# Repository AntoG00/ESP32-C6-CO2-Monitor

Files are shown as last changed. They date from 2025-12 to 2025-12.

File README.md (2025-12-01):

# ESP32-C6 E-Paper Air Quality Monitor

A high-precision, open-hardware environmental monitor designed to track CO2, Temperature, and Humidity levels. The device is built around the RISC-V based ESP32-C6 and features a raw E-Paper panel with a custom-designed boost driver to ensure zero light pollution and minimal thermal self-heating.

Schematic
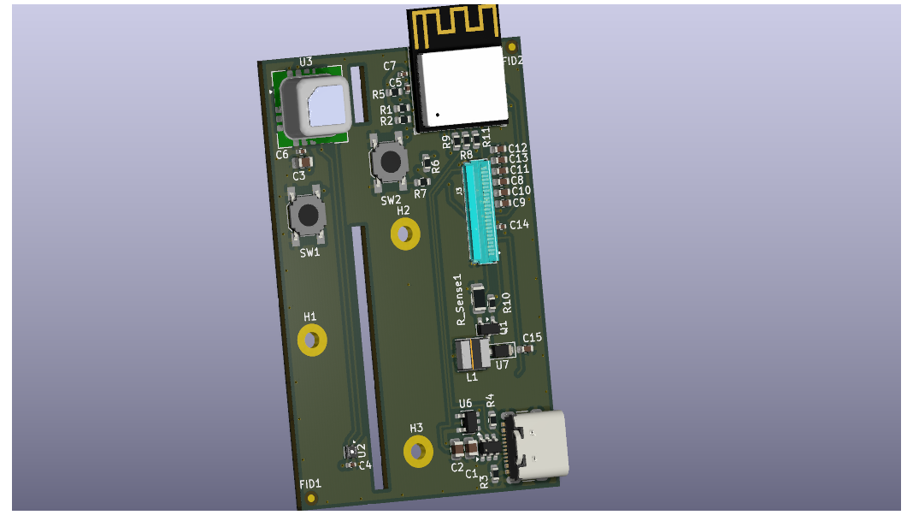
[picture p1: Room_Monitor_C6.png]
3D Render of the PCB


## Key Features
*   **MCU:** Espressif **ESP32-C6-Mini-1** (RISC-V, Wi-Fi 6, BLE 5, Zigbee).
*   **Sensors:**
    *   **SCD43 (Sensirion):** Photoacoustic NDIR CO2 sensor for high-accuracy indoor air quality monitoring.
    *   **SHT45-AD1F (Sensirion):** Ultra-high precision (±1.0% RH, ±0.1°C) temperature and humidity sensor with integrated PTFE membrane for protection.
*   **Display:** **Pervasive Displays E2266QS0F1** (2.66" E-Paper/E-Ink).
*   **Power:** USB-C powered via a high-efficiency, low-noise LDO (**TLV75733**). Designed for continuous operation without batteries.

## Engineering Design Decisions
This project involved several specific hardware design challenges:

1.  **Thermal Isolation (Mechanical/Electrical):** To prevent the heat generated by the MCU and voltage regulators from biasing the sensitive SHT45 and SCD43 readings, the sensors are physically isolated on the PCB using milling slots (thermal cutouts) and thin connecting bridges.
2.  **Custom E-Paper Driver:** Instead of using a pre-made display module, I integrated the high-voltage boost converter (generating ~15V) directly onto the main PCB using a specialized power inductor ($I_{sat} > 800mA$), N-Channel MOSFET, and Schottky diode topology.
3.  **Signal Integrity:** The schematic includes specific filtering for the photoacoustic sensor's peak current demands and a dedicated boot-strapping circuit to ensure reliable flashing via the native USB interface.

## PCB Layout & Thermal Engineering
The design utilizes a **4-layer stack-up** to ensure solid Ground return paths and stable power delivery for the ESP32's RF radio.

A dedicated **thermal isolation slot** separates the board into two distinct thermal zones:
*   **Right Side (Hot Zone):** Contains the ESP32 MCU, Power Regulation, and Boost Converter.
*   **Left Side (Cold Zone):** Contains the environmental sensors, connected only by narrow FR4 bridges to minimize thermal conductivity.

## Status
*   [x] Schematic Design & Verification
*   [x] PCB Layout (4-Layer)
*   [ ] Manufacturing & Assembly

## License
MIT License

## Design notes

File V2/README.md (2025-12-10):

# Hardware V2 – ESP32‑C6 + SEN66 + 4.2" E‑Ink

This is the second hardware revision of the project. V2 replaces the SCD43 + SHT45 combo with a single Sensirion **SEN66** environmental sensor and upgrades the display.

## Main Components

- **MCU:** Espressif **ESP32‑C6 Mini**
  - Wi‑Fi 6 + BLE / 802.15.4 capable (WiFi 6, Zigbee, Thread)
- **Sensor:** Sensirion **SEN66**
  - PM1, PM2.5, PM4, PM10
  - Temperature, Relative Humidity
  - VOC Index, NOx Index, CO₂
- **Display:** Pervasive Displays **4.2" Spectra E2417QS0A3**
  - 3‑color E‑Ink
- **Status LED:** Inolux **IN‑PI33TBTPRPGPB** multi‑color LED
  - Used for debug / status indication via color patterns

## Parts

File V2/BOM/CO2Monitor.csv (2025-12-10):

Reference | Qty | Value | DNP | Exclude from BOM | Exclude from Board | Footprint | Datasheet
C1,C2,C3,C4,C5,C6,C7,C13 | 8 | 1µF 50V |  |  |  | Capacitor_SMD:C_0603_1608Metric | ~
C8,C9 | 2 | 4.7µF 25V |  |  |  | Capacitor_SMD:C_1206_3216Metric | ~
C10,C12,C15,C17,C18 | 5 | 0.1µF 16V |  |  |  | Capacitor_SMD:C_0402_1005Metric | ~
C11,C14,C16 | 3 | 10µF 16V |  |  |  | Capacitor_SMD:C_0805_2012Metric | ~
C19,C20 | 2 | 22µF 10V |  |  |  | Capacitor_SMD:C_1206_3216Metric | ~
D1,D2,D3 | 3 | SS2040FL |  |  |  | SS2040FL:SODFL3618X110N | https://4donline.ihs.com/images/VipMasterIC/IC/PNJI/PNJI-S-A0003671102/PNJI-S-A0003671102-1.pdf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
D4 | 1 | IN-PI33TBTPRPGPB |  |  |  | IN-PI33TBTPRPGPB:LED_IN-PI33TBTPRPGPB
H1,H2,H3 | 3 | MountingHole_Pad |  | Excluded from BOM |  | MountingHole:MountingHole_3.2mm_M3_ISO14580_Pad | ~
J1 | 1 | FH34SRJ-24S-0.5SH50 |  |  |  | FH34SRJ-24S-0.5SH(50):CONN24x1_FH34SRJ-24S-0.5SH50_HIR | FH34SRJ-24S-0.5SH50
J2 | 1 | USB_C_Receptacle_USB2.0_16P |  |  |  | USB4145-03-0230-C:GCT_USB4145-03-0230-C_REVA2 | https://www.usb.org/sites/default/files/documents/usb_type-c.zip
J3 | 1 | Conn_01x06 |  |  |  | Connector_JST:JST_GH_SM06B-GHS-TB_1x06-1MP_P1.25mm_Horizontal | ~
L1 | 1 | 10 uH |  |  |  | Inductor_SMD:L_Bourns-SRN4018 | ~
L2 | 1 | 3.9 uH |  |  |  | Inductor_SMD:L_Bourns-SRN4018 | ~
Q1 | 1 | Si1308EDL |  |  |  | Package_TO_SOT_SMD:SOT-323_SC-70 | https://www.vishay.com/docs/63399/si1308edl.pdf
Q2 | 1 | SI2301-TP |  |  |  | SI2301-TP:SOT95P237X125-3N | https://mccsemi.com/pdf/Products/SI2301(SOT-23).pdf
R1 | 1 | 0.47Ω 1% |  |  |  | Resistor_SMD:R_1206_3216Metric | ~
R2 | 1 | 100kΩ |  |  |  | Resistor_SMD:R_0603_1608Metric | ~
R3,R4 | 2 | 5.1kΩ |  |  |  | Resistor_SMD:R_0603_1608Metric | ~
R5,R6,R7,R8,R11,R12 | 6 | 10kΩ |  |  |  | Resistor_SMD:R_0603_1608Metric | ~
R9,R10,R14 | 3 | 22Ω |  |  |  | Resistor_SMD:R_0603_1608Metric | ~
R13 | 1 | 1kΩ |  |  |  | Resistor_SMD:R_0603_1608Metric | ~
SW1,SW2 | 2 | 2-1437565-8 |  |  |  | TE Connectivity 2-1437565-8:SW_2-1437565-8
U1 | 1 | USBLC6-2SC6 |  |  |  | Package_TO_SOT_SMD:SOT-23-6 | https://www.st.com/resource/en/datasheet/usblc6-2.pdf
U2 | 1 | SN74AHCT1G125DBVR |  |  |  | SN74AHCT1G125DBVR:SOT95P280X145-5N
U3 | 1 | AP63203WU |  |  |  | Package_TO_SOT_SMD:TSOT-23-6 | https://www.diodes.com/assets/Datasheets/AP63200-AP63201-AP63203-AP63205.pdf
U4 | 1 | ESP32-C6-MINI-1/U |  |  |  | PCM_Espressif:ESP32-C6-MINI-1 | https://www.espressif.com/sites/default/files/documentation/esp32-c6-mini-1_datasheet_en.pdf

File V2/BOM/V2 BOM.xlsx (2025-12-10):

 |  |  | BOM
Item # | *Designator | *Qty | Manufacturer | *Mfg Part # | Description / Value | *Package/Footprint | Your Instructions / Notes
1 | C1,C2,C3,C4,C5,C6,C7,C13 | 8 |  | 1µF 50V | Cap Ceramic 1µF 50V X7R 10% | Capacitor_SMD:C_0603_1608Metric
2 | C8,C9 | 2 |  | 4.7µF 25V | Cap Ceramic 4.7µF 25V X7R 10% | Capacitor_SMD:C_1206_3216Metric
3 | C10,C12,C15,C17,C18 | 5 |  | 0.1µF 16V | Cap Ceramic 0.1µF 16V (or 25V) X7R 10% | Capacitor_SMD:C_0402_1005Metric
4 | C11,C14,C16 | 3 |  | 10µF 16V | Cap Ceramic 10µF 16V (or 25V) X5R/X7R 10% | Capacitor_SMD:C_0805_2012Metric
5 | C19,C20 | 2 |  | 22µF 10V | Cap Ceramic 22µF 10V (or 16V) X5R/X7R 20% | Capacitor_SMD:C_1206_3216Metric
6 | D1,D2,D3 | 3 | Panjit | SS2040FL_R1_00001 | Schottky Diodes & Rectifiers 40V,Schottky,SOD-123FL,2A | SS2040FL:SODFL3618X110N | https://www2.mouser.com/datasheet/3/3736/1/774A80C0874A6CB8090245F2BB384B93521894600CCD1BA14FFDA33ECB6A733A.pdf
7 | D4 | 1 | Inolux | IN-PI33TBTPRPGPB | Multi-Colour LEDs Top View / PLCC / 3.5 x 3.5 x 1.95 / 4-pin / Tricolor with IC | IN-PI33TBTPRPGPB:LED_IN-PI33TBTPRPGPB | https://www2.mouser.com/datasheet/3/760/1/IN_PI33TBTPRPGPB_v1.2.pdf
8 | J1 | 1 | Hirose Connector | FH34SRJ-24S-0.5SH50 | FFC & FPC Connectors 24POS .5MM | FH34SRJ-24S-0.5SH(50):CONN24x1_FH34SRJ-24S-0.5SH50_HIR | https://www2.mouser.com/datasheet/3/731/1/FH34SRJ_24S_0.5SH_50__CL0580_1255_6_50_2DDrawing_0001483059.pdf
9 | J2 | 1 | GCT | USB4145-03-0230-C | USB Connectors USB-C Rec 3u" Vert 16P SMT 2.3mm TH stakes H7.46mm T+R+Cap | USB4145-03-0230-C:GCT_USB4145-03-0230-C_REVA2 | https://www.mouser.com/catalog/specsheets/Global_Connector_Technology_usb4145.pdf
10 | J3 | 1 | JST Commercial | SM06B-GHS-TB | Headers & Wire Housings | Connector_JST:JST_GH_SM06B-GHS-TB_1x06-1MP_P1.25mm_Horizontal | https://www2.mouser.com/datasheet/3/1070/1/eGH.pdf
11 | L1 | 1 | Bourns | SRN4018-100M | Power Inductors - SMD 10uH 20% SMD 4018 | Inductor_SMD:L_Bourns-SRN4018 | Power Inductor, Shielded, Isat > 0.5A, DCR < 0.5Ω
12 | L2 | 1 | Bourns | SRN5040-4R7M | Power Inductors - SMD 4.7uH 20% SMD 5040 | SRN5040:INDPM5050X400N | 4.7 µH SMD shielded/semi‑shielded power inductor, Irms ≥ 3.0 A, Isat ≥ 3.0 A, DCR ≤ 40 mΩ, 5040 package
13 | Q1 | 1 | Vishay | SI1308EDL-T1-GE3 | MOSFETs 30V Vds 12V Vgs SC70-3 | Package_TO_SOT_SMD:SOT-323_SC-70 | https://www.vishay.com/doc?63399
14 | Q2 | 1 | Micro Commercial Components (MCC) | SI2301-TP | MOSFETs P-CH -20V -2.8A 8S | SI2301-TP:SOT95P237X125-3N | https://eu.mouser.com/datasheet/3/225/1/SI2301(SOT-23).pdf
15 | R1 | 1 |  | 0.47Ω 1% | Res Current Sense 0.47Ω 1% 1/4W | Resistor_SMD:R_1206_3216Metric
16 | R2 | 1 |  | 100kΩ | Res Thick Film 100kΩ 1% 1/10W | Resistor_SMD:R_0603_1608Metric
17 | R3,R4 | 2 |  | 5.1kΩ | Res Thick Film 5.1kΩ 1% 1/10W | Resistor_SMD:R_0603_1608Metric
18 | R5,R6,R7,R8,R11,R12 | 6 |  | 10kΩ | Res Thick Film 10kΩ 1% 1/10W | Resistor_SMD:R_0603_1608Metric
19 | R9,R10,R14 | 3 |  | 22Ω | Res Thick Film 22Ω 1% 1/10W | Resistor_SMD:R_0603_1608Metric
20 | R13 | 1 |  | 1kΩ | Res Thick Film 1kΩ 1% 1/10W | Resistor_SMD:R_0603_1608Metric
21 | SW1,SW2 | 2 | TE Connectivity / P&B | 2-1437565-8 | Tactile Switches TACTILE 260G FORCE S | TE Connectivity 2-1437565-8:SW_2-1437565-8 | Or Generic 6x6mm SMD Switch
22 | U1 | 1 | STMicroelectronics | USBLC6-2SC6 | ESD Protection Diodes / TVS Diodes ESD Protection Low Cap | Package_TO_SOT_SMD:SOT-23-6 | https://www.st.com/resource/en/datasheet/usblc6-2.pdf
23 | U2 | 1 | Texas Instruments | SN74AHCT1G125DBVR | Buffers & Line Drivers Tri-State Single Bus A 595-SN74AHCT1G125 A 595-SN74AHCT1G125DBV | SN74AHCT1G125DBVR:SOT95P280X145-5N | https://www.ti.com/lit/gpn/sn74ahct1g125
24 | U3 | 1 | Diodes Incorporated | AP63203WU | Switching Voltage Regulators DCDC Conv HV Buck TSOT26 T&R 3K | Package_TO_SOT_SMD:TSOT-23-6 | https://4donline.ihs.com/images/VipMasterIC/IC/DIOD/DIOD-S-A0007089856/DIOD-S-A0007089856-1.pdf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
25 | U4 | 1 | Espressif Systems | ESP32-C6-MINI-1-H8 | ESP32-C6-MINI-1-H8 | PCM_Espressif:ESP32-C6-MINI-1 | https://www.mouser.com/catalog/specsheets/Espressif_Systems_esp32-c6-mini-1_mini-1u_datasheet_en.pdf
Need a quick and accurante quote? Need an efficient production? Please read SMT Ordering Necessary Files & Info in 1 minute. Thank you very much!
Click for Instructions on How to Create a BOM (https://www.pcbway.com/blog/PCB_Assembly/How_to_Build_a_BOM__Bill_Of_Materials_.html)

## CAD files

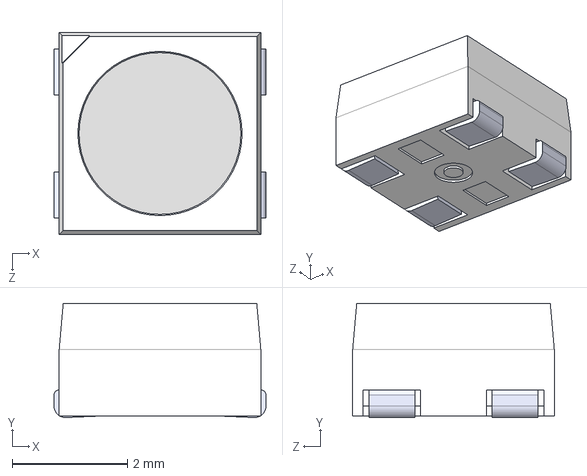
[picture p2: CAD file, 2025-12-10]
V2/Symbols/IN-PI33TBTPRPGPB/IN-PI33TBTPRPGPB.step
3.68 x 1.98 x 3.50 mm

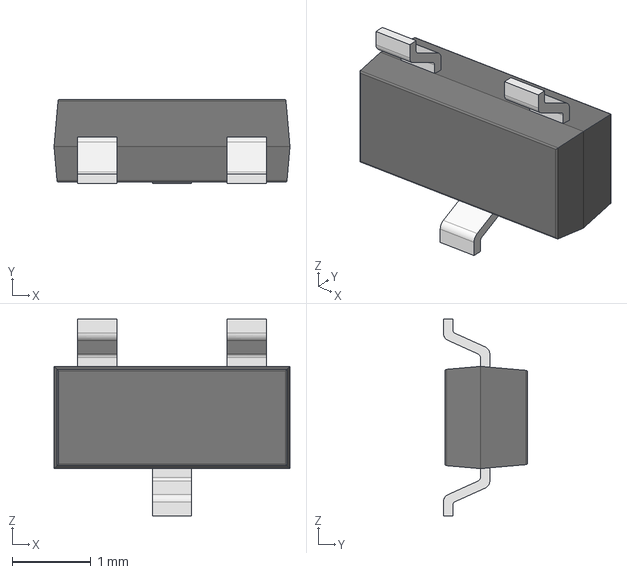
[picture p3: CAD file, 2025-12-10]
V2/Symbols/SI2301-TP/3D/SI2301-TP.stp
3.00 x 1.07 x 2.50 mm
��1
��2

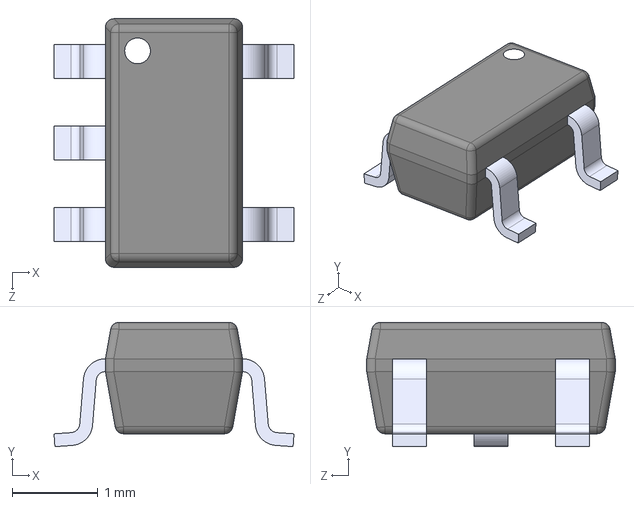
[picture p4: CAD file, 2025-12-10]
V2/Symbols/SN74AHCT1G125DBVR/SN74AHCT1G125DBVR.step
2.80 x 1.45 x 2.90 mm

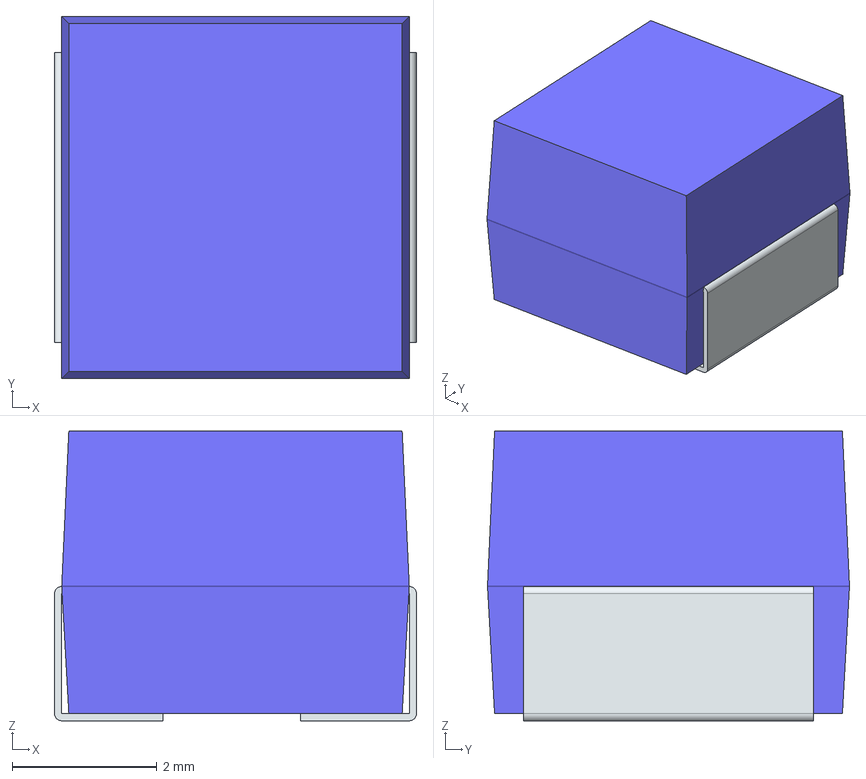
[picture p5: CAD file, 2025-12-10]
V2/Symbols/SRN5040-4R7M/3D/SRN5040-4R7M.stp
5.00 x 5.00 x 4.00 mm
FilletPin1
FilletPin2

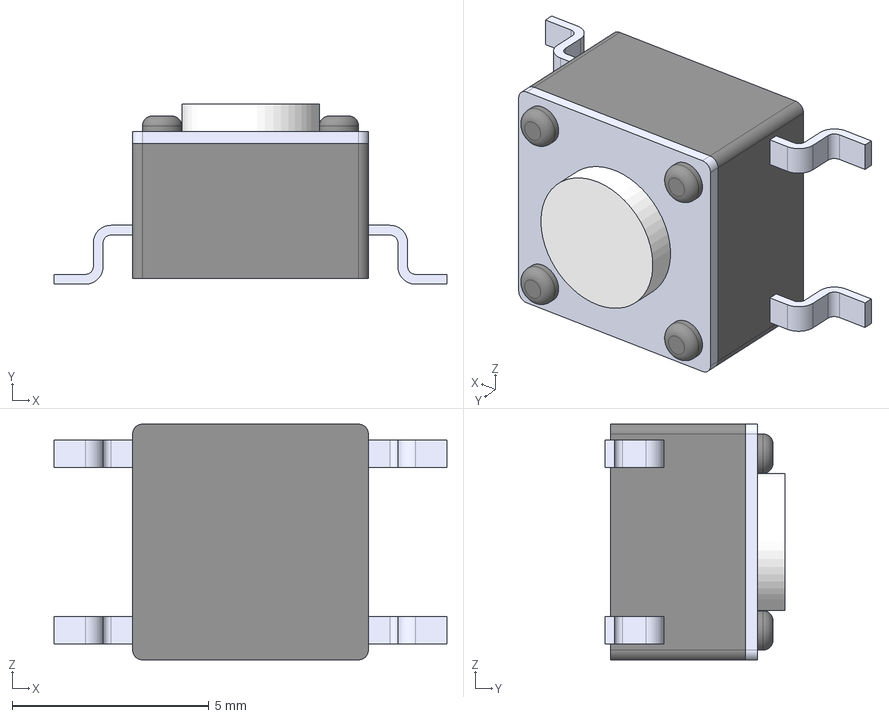
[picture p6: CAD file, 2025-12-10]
V2/Symbols/TE Connectivity 2-1437565-8/2-1437565-8.step
10.0 x 4.59 x 6.00 mm
Body003 (Mirror #1)
Body003 (Mirror #3)
Body003 (Mirror #2)

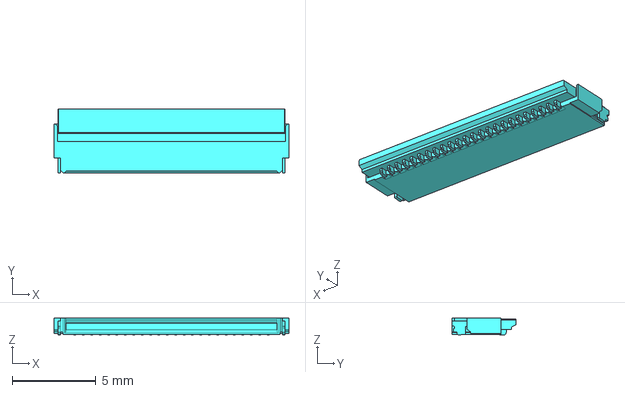
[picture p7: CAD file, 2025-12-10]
V2/Symbols/ul_FH34SRJ-24S-0-5SH-50-/FH34SRJ-24S-0.5SH.stp
14.0 x 3.80 x 1.00 mm

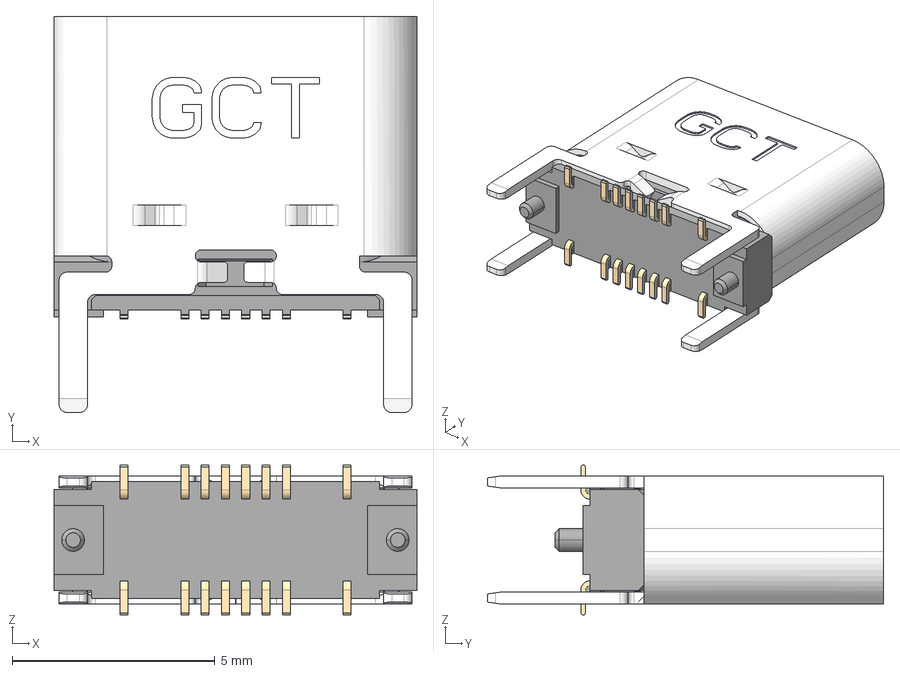
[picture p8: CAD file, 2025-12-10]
V2/Symbols/ul_USB4145-03-0230-C/usb4145-03-0230-c.stp
8.95 x 9.76 x 3.69 mm

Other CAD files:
V2/Symbols/ul_FH34SRJ-24S-0-5SH-50-/FH34SRJ-24S-0.5SH.igs

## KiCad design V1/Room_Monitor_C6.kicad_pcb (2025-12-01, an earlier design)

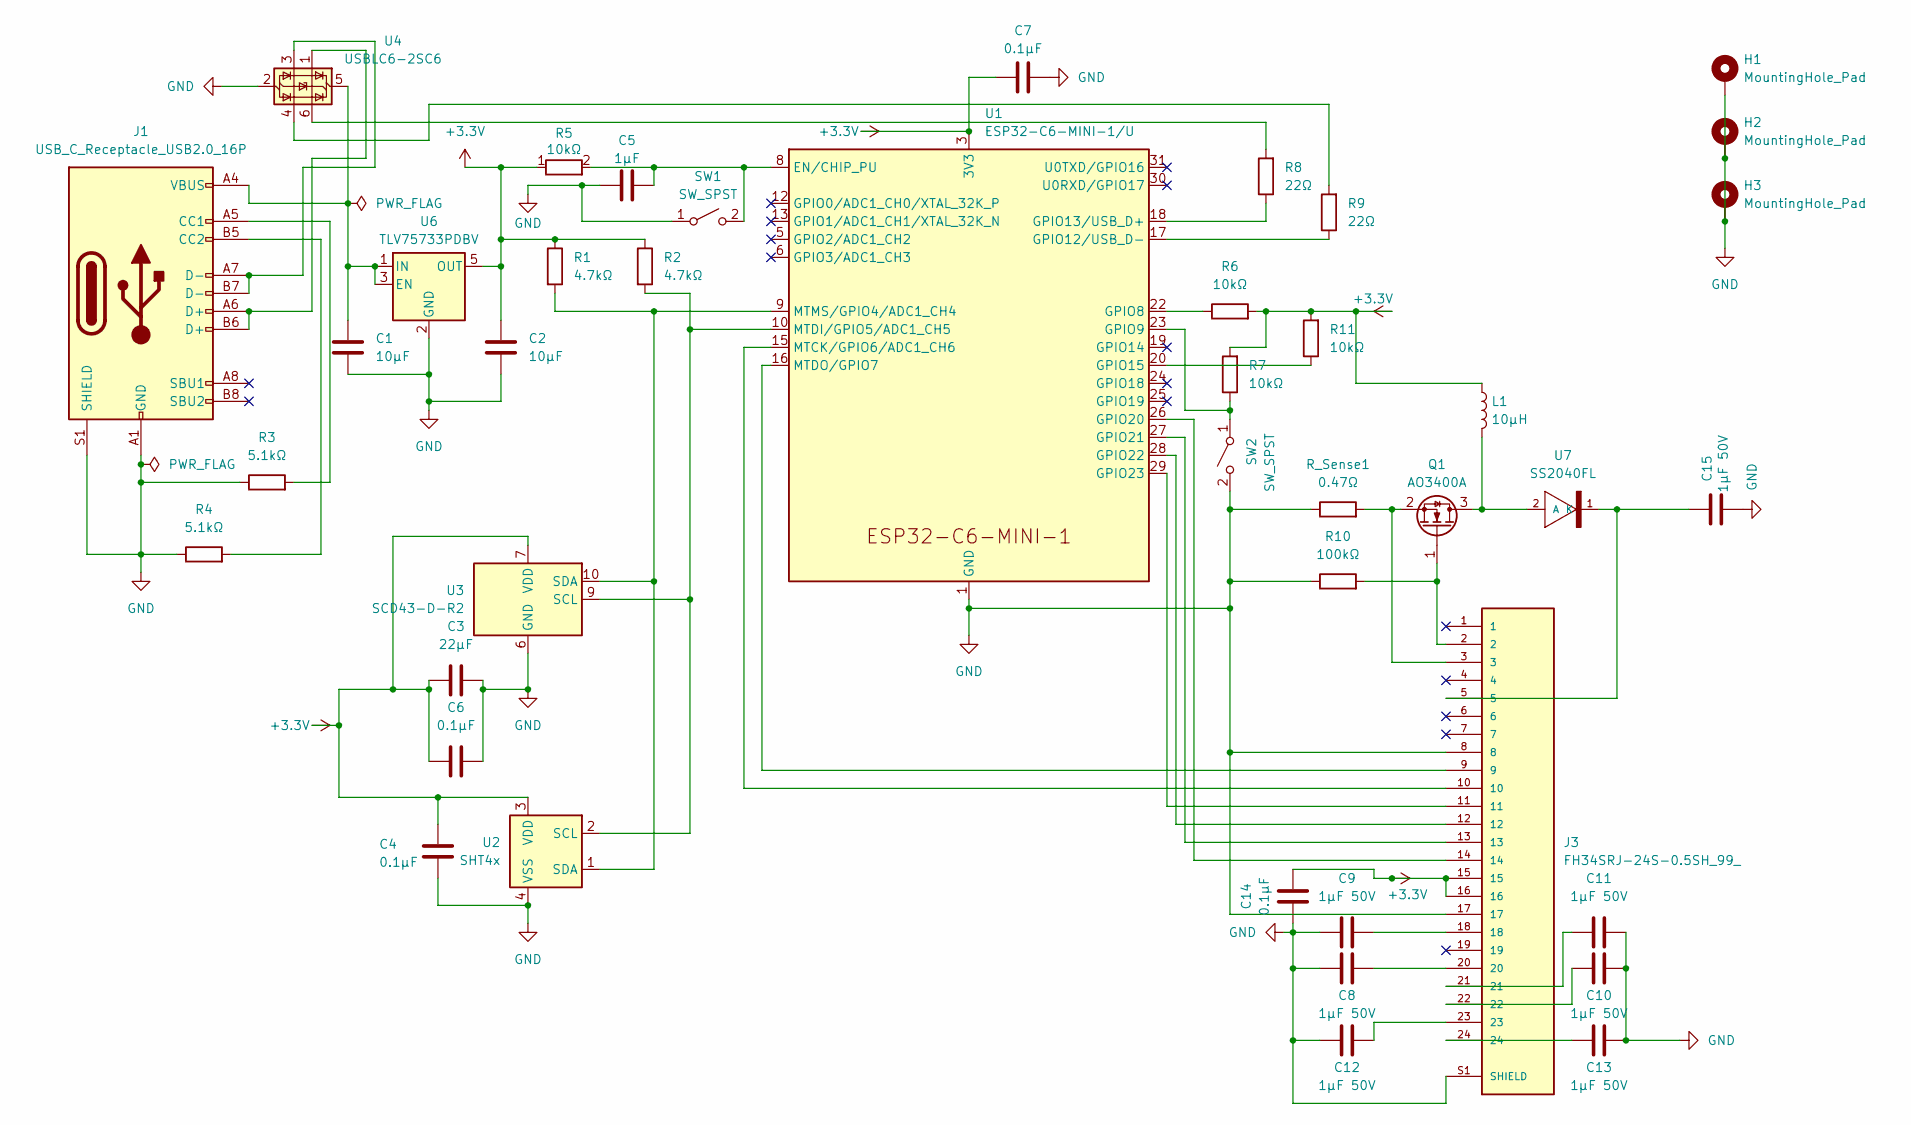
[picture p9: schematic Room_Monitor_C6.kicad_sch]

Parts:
C1, C2: 10µF; C_0805_2012Metric
C3: 22µF; C_0805_2012Metric
C4, C6, C7, C14: 0.1µF; C_0402_1005Metric
C5: 1µF; C_0402_1005Metric
C8, C9, C10, C11, C12, C13, C15: 1µF 50V; C_0603_1608Metric
H1, H2, H3: MountingHole_Pad; MountingHole_2.2mm_M2_Pad
J1: USB_C_Receptacle_USB2.0_16P; USB_C_Receptacle_GCT_USB4105-xx-A_16P_TopMnt_Horizontal
J3: FH34SRJ-24S-0.5SH_99_; HRS_FH34SRJ-24S-0.5SH_99_; PARTREV NA; DigiKey_Part_Number H124725CT-ND
L1: 10µH; L_Taiyo-Yuden_NR-40xx
Q1: AO3400A; SOT-23
R1, R2: 4.7kΩ; R_0603_1608Metric
R3, R4: 5.1kΩ; R_0603_1608Metric
R5, R6, R7, R11: 10kΩ; R_0603_1608Metric
R8, R9: 22Ω; R_0603_1608Metric
R10: 100kΩ; R_0603_1608Metric
R_Sense1: 0.47Ω; R_1206_3216Metric
SW1, SW2: SW_SPST; SW_SPST_SKQG_WithoutStem
U1: ESP32-C6-MINI-1/U; ESP32-C6-MINI-1
U2: SHT4x; Sensirion_DFN-4_1.5x1.5mm_P0.8mm_SHT4x_NoCentralPad
U3: SCD43-D-R2; Sensirion_SCD4x-1EP_10.1x10.1mm_P1.25mm_EP4.8x4.8mm
U4: USBLC6-2SC6; SOT-23-6
U6: TLV75733PDBV; SOT-23-5
U7: SS2040FL; D_SOD-123F

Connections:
+3.3V: C2.1, C3.1, C4.2, C6.1, C7.1, C14.2, J3.15, J3.16, L1.1, R1.1, R2.1, R5.1, R6.2, R7.2, R11.2, U1.3 (3V3), U2.3 (VDD), U3.7 (VDD), U3.19 (VDD), U6.5 (OUT)
GND: C1.2, C2.2, C3.2, C4.1, C5.1, C6.2, C7.2, C8.2, C9.1, C10.1, C11.2, C12.2, C13.1, C14.1, C15.1, H1.1, H2.1, H3.1, J1.A1 (GND), J1.A12 (GND), J1.B1 (GND), J1.B12 (GND), J1.S1 (SHIELD), J3.8, J3.17, J3.S1 (SHIELD), J3.S2 (SHIELD), R3.1, R4.1, R10.1, R_Sense1.1, SW1.1 (A), SW2.2 (B), U1.1 (GND), U1.2 (GND), U1.11 (GND), U1.14 (GND), U1.36 (GND), U1.37 (GND), U1.38 (GND), U1.39 (GND), U1.40 (GND), U1.41 (GND), U1.42 (GND), U1.43 (GND), U1.44 (GND), U1.45 (GND), U1.46 (GND), U1.47 (GND), U1.48 (GND), U1.49 (GND), U1.50 (GND), U1.51 (GND), U1.52 (GND), U1.53 (GND), U2.4 (VSS), U3.6 (GND), U3.20 (GND), U3.21 (GND), U4.2 (GND), U6.2 (GND)
unnamed: C8.1, J3.20
unnamed: C9.2, J3.18
unnamed: C10.2, J3.22
unnamed: C11.1, J3.21
unnamed: C12.1, J3.23
unnamed: C13.2, J3.24
unnamed: J1.A5 (CC1), R3.2
unnamed: J1.B5 (CC2), R4.2
unnamed: J1.A6 (D+), J1.B6 (D+), U4.1 (I/O1)
unnamed: J1.A7 (D-), J1.B7 (D-), U4.3 (I/O2)
unnamed: L1.2, Q1.3 (D), U7.2 (A)
unnamed: J3.2, Q1.1 (G), R10.2
unnamed: J3.3, Q1.2 (S), R_Sense1.2
unnamed: R8.2, U4.6 (I/O1)
unnamed: R9.2, U4.4 (I/O2)
unnamed: C5.2, R5.2, SW1.2 (B), U1.8 (EN/CHIP_PU)
unnamed: R7.1, SW2.1 (A), U1.23 (GPIO9)
unnamed: R6.1, U1.22 (GPIO8)
unnamed: R9.1, U1.17 (GPIO12/USB_D-)
unnamed: R8.1, U1.18 (GPIO13/USB_D+)
unnamed: R11.1, U1.20 (GPIO15)
unnamed: J3.14, U1.26 (GPIO20)
unnamed: J3.13, U1.27 (GPIO21)
unnamed: J3.12, U1.28 (GPIO22)
unnamed: J3.11, U1.29 (GPIO23)
unnamed: J3.10, U1.15 (MTCK/GPIO6/ADC1_CH6)
unnamed: R2.2, U1.10 (MTDI/GPIO5/ADC1_CH5), U2.2 (SCL), U3.9 (SCL)
unnamed: J3.9, U1.16 (MTDO/GPIO7)
unnamed: R1.2, U1.9 (MTMS/GPIO4/ADC1_CH4), U2.1 (SDA), U3.10 (SDA)
unnamed: C1.1, J1.A4 (VBUS), J1.A9 (VBUS), J1.B4 (VBUS), J1.B9 (VBUS), U4.5 (VBUS), U6.1 (IN), U6.3 (EN)
unnamed: C15.2, J3.5, U7.1 (K)

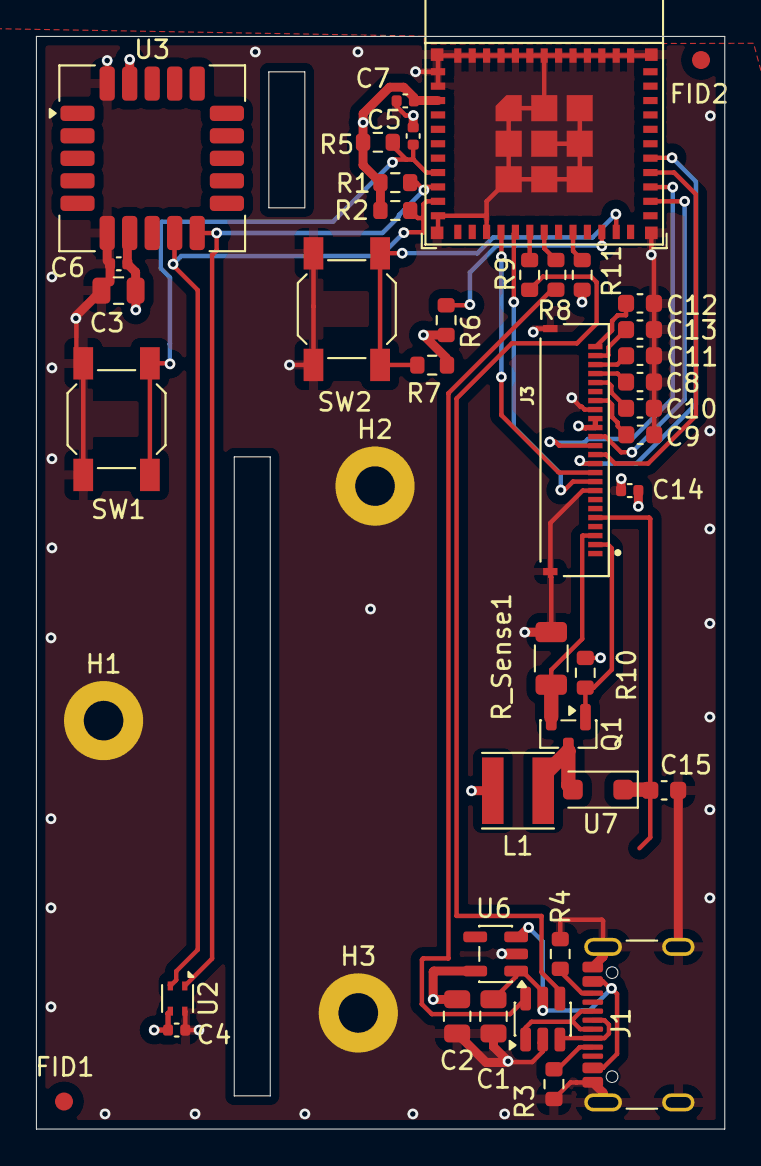
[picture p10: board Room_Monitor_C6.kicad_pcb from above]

Board: 4 copper layers, 38.2 x 60.7 mm, 44 parts (0 on the bottom side), 33 nets.

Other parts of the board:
FID1, FID2: Fiducial; Fiducial_1mm_Mask2mm

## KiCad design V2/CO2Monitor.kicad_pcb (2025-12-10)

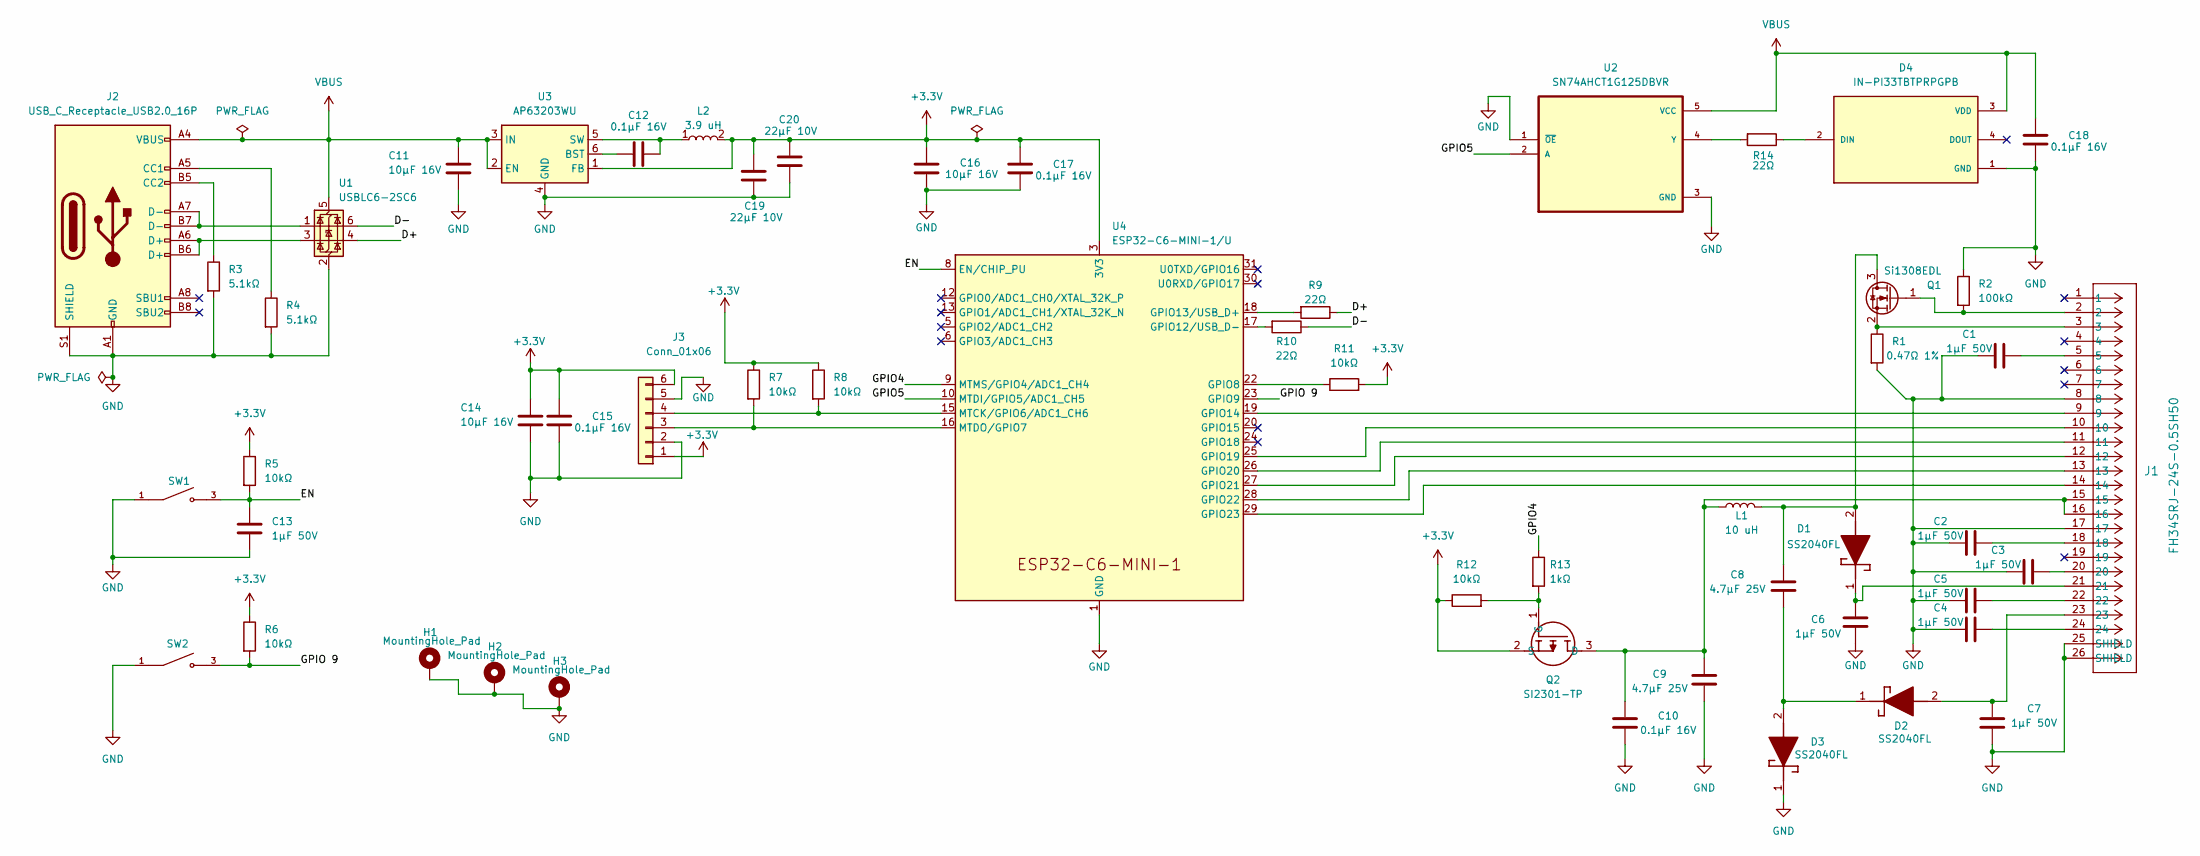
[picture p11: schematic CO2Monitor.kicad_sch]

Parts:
C1, C2, C3, C4, C5, C6, C7, C13: 1µF 50V; C_0603_1608Metric
C8, C9: 4.7µF 25V; C_1206_3216Metric
C10, C12, C15, C17, C18: 0.1µF 16V; C_0402_1005Metric
C11, C14, C16: 10µF 16V; C_0805_2012Metric
C19, C20: 22µF 10V; C_1206_3216Metric
D1, D2, D3: SS2040FL; SODFL3618X110N; Mouser Part Number 241-SS2040FLR100001
D4: IN-PI33TBTPRPGPB; LED_IN-PI33TBTPRPGPB; PARTREV 1.2
H1, H2, H3: MountingHole_Pad; MountingHole_3.2mm_M3_ISO14580_Pad
J1: FH34SRJ-24S-0.5SH50; CONN24x1_FH34SRJ-24S-0.5SH50_HIR
J2: USB_C_Receptacle_USB2.0_16P; GCT_USB4145-03-0230-C_REVA2
J3: Conn_01x06; JST_GH_SM06B-GHS-TB_1x06-1MP_P1.25mm_Horizontal
L1: 10 uH; L_Bourns-SRN4018
L2: 3.9 uH; INDPM5050X400N
Q1: Si1308EDL; SOT-323_SC-70
Q2: SI2301-TP; SOT95P237X125-3N; Mouser Part Number 833-SI2301-TP
R1: 0.47Ω 1%; R_1206_3216Metric
R2: 100kΩ; R_0603_1608Metric
R3, R4: 5.1kΩ; R_0603_1608Metric
R5, R6, R7, R8, R11, R12: 10kΩ; R_0603_1608Metric
R9, R10, R14: 22Ω; R_0603_1608Metric
R13: 1kΩ; R_0603_1608Metric
SW1, SW2: 2-1437565-8; SW_2-1437565-8; PARTREV V
U1: USBLC6-2SC6; SOT-23-6
U2: SN74AHCT1G125DBVR; SOT95P280X145-5N
U3: AP63203WU; TSOT-23-6
U4: ESP32-C6-MINI-1/U; ESP32-C6-MINI-1

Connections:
+3.3V: C14.1, C15.1, C16.2, C17.1, C19.1, C20.1, J3.1, J3.6, L2.2, Q2.2 (S), R5.1, R6.1, R7.1, R8.1, R11.2, R12.1, U3.1 (FB), U4.3 (3V3)
/D+: R9.1, U1.4 (I/O2)
/D-: R10.1, U1.6 (I/O1)
/EN: C13.2, R5.2, SW1.3, SW1.4, U4.8 (EN/CHIP_PU)
/GPIO4: R13.1, U4.9 (MTMS/GPIO4/ADC1_CH4)
/GPIO5: U2.2 (A), U4.10 (MTDI/GPIO5/ADC1_CH5)
/GPIO 9: R6.2, SW2.3, SW2.4, U4.23 (GPIO9)
GND: C1.1, C2.1, C3.1, C4.1, C5.1, C6.1, C7.1, C9.2, C10.2, C11.2, C13.1, C14.2, C15.2, C16.1, C17.2, C18.2, C19.2, C20.2, D3.1 (K), D4.1 (GND), H1.1, H2.1, H3.1, J1.8, J1.17, J1.25 (SHIELD), J1.26 (SHIELD), J2.A1 (GND), J2.A12 (GND), J2.B1 (GND), J2.B12 (GND), J2.S1 (SHIELD), J3.2, J3.5, R1.2, R2.1, R3.2, R4.2, SW1.1, SW1.2, SW2.1, SW2.2, U1.2 (GND), U2.1 (~OE), U2.3 (GND), U3.4 (GND), U4.1 (GND), U4.2 (GND), U4.11 (GND), U4.14 (GND), U4.36 (GND), U4.37 (GND), U4.38 (GND), U4.39 (GND), U4.40 (GND), U4.41 (GND), U4.42 (GND), U4.43 (GND), U4.44 (GND), U4.45 (GND), U4.46 (GND), U4.47 (GND), U4.48 (GND), U4.49 (GND), U4.50 (GND), U4.51 (GND), U4.52 (GND), U4.53 (GND)
unnamed: C1.2, J1.5
unnamed: C2.2, J1.18
unnamed: C3.2, J1.20
unnamed: C4.2, J1.24
unnamed: C5.2, J1.22
unnamed: C8.2, D1.2 (A), L1.2, Q1.3 (D)
unnamed: C6.2, D1.1 (K), J1.21
unnamed: C7.2, D2.2 (A), J1.23
unnamed: C8.1, D2.1 (K), D3.2 (A)
unnamed: D4.2 (DIN), R14.1
unnamed: J2.A5 (CC1), R4.1
unnamed: J2.B5 (CC2), R3.1
unnamed: J2.A6 (D+), J2.B6 (D+), U1.3 (I/O2)
unnamed: J2.A7 (D-), J2.B7 (D-), U1.1 (I/O1)
unnamed: J3.3, R7.2, U4.16 (MTDO/GPIO7)
unnamed: J3.4, R8.2, U4.15 (MTCK/GPIO6/ADC1_CH6)
unnamed: J1.2, Q1.1 (G), R2.2
unnamed: J1.3, Q1.2 (S), R1.1
unnamed: C9.1, C10.1, J1.15, J1.16, L1.1, Q2.3 (D)
unnamed: Q2.1 (G), R12.2, R13.2
unnamed: R14.2, U2.4 (Y)
unnamed: C12.1, U3.6 (BST)
unnamed: C12.2, L2.1, U3.5 (SW)
unnamed: R11.1, U4.22 (GPIO8)
unnamed: R10.2, U4.17 (GPIO12/USB_D-)
unnamed: R9.2, U4.18 (GPIO13/USB_D+)
unnamed: J1.9, U4.19 (GPIO14)
unnamed: J1.10, U4.25 (GPIO19)
unnamed: J1.11, U4.26 (GPIO20)
unnamed: J1.12, U4.27 (GPIO21)
unnamed: J1.13, U4.28 (GPIO22)
unnamed: J1.14, U4.29 (GPIO23)
VBUS: C11.1, C18.1, D4.3 (VDD), J2.A4 (VBUS), J2.A9 (VBUS), J2.B4 (VBUS), J2.B9 (VBUS), U1.5 (VBUS), U2.5 (VCC), U3.2 (EN), U3.3 (IN)

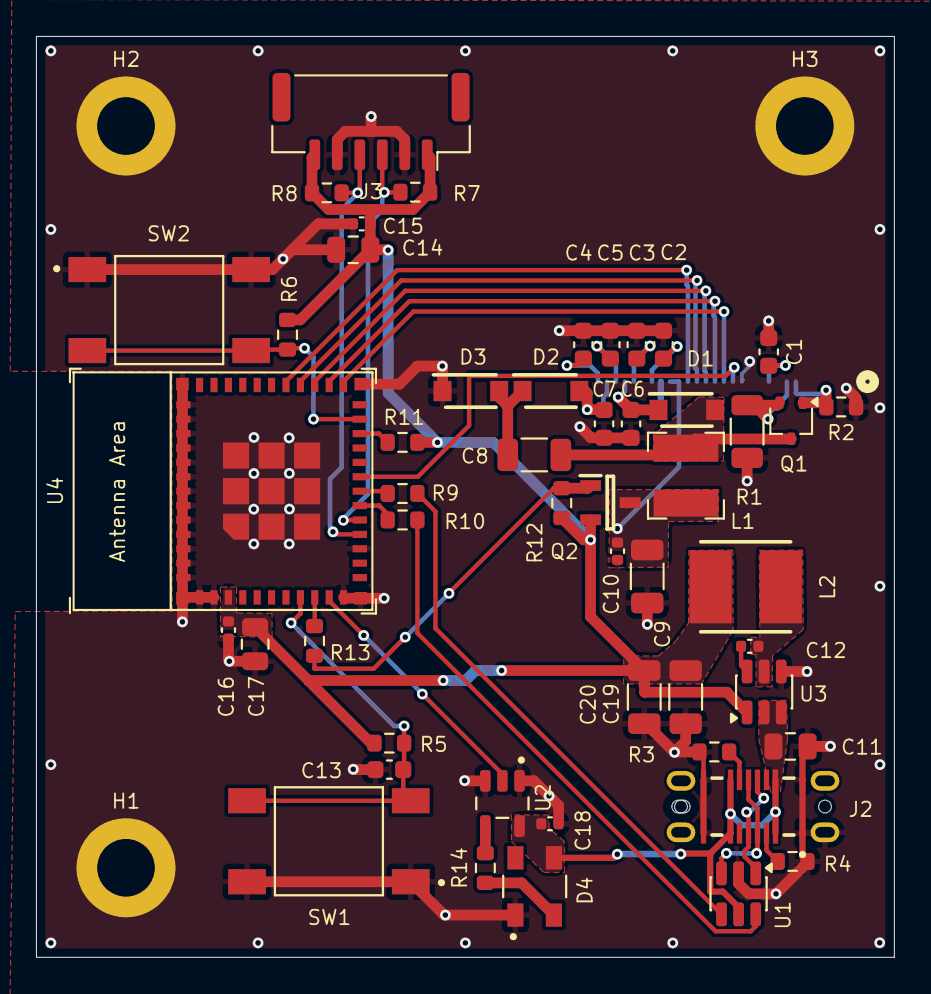
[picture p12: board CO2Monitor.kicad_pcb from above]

Board: 2 copper layers, 47.7 x 51.2 mm, 54 parts (1 on the bottom side), 41 nets.

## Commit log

2025-11-29 Initial Schematic Release
    [Room_Monitor_C6.kicad_pcb, Room_Monitor_C6.kicad_sch]
2025-12-01 Completed 4-layer PCB layout
    [Room_Monitor_C6.kicad_pcb, Room_Monitor_C6.kicad_sch]
2025-12-10 Added v2 folder/readme for new SEN66 + ESP32C6 board
2025-12-10 Add v1 folder for original board
2025-12-10 Move V1 files in correct folder
    [Room_Monitor_C6.kicad_pcb]
